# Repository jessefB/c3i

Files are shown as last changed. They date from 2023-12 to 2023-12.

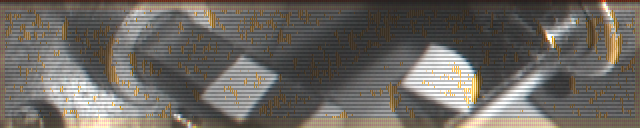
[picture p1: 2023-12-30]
code/raspiraw-master/res/out.1000.ppm.d.png

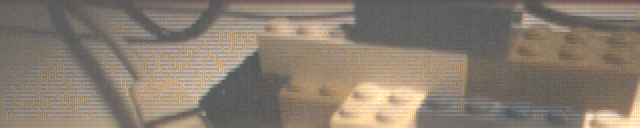
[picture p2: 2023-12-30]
code/raspiraw-master/res/out.0123.ppm.d.png

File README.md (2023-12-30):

# c3i
Composite to CSI2 Camera Interface (aka CCCI aka c3i)

### Purpose
Add a readily-available composite video camera (sold as 'backup cameras') to Raspberry Pi over a MIPI CSI2 camera interface

### Basic function
The ADV7280-M chip does all the magic, automatically detecting the composite video format (NTSC or PAL) and converting that to YCrCb 4:2:2 video stream. The -M variant of this chip adds a MIPI CSI2 conversion block, providing a single lane output MIPI data stream. Raspberry Pi's have dual lane MIPI channels, but according to [this](https://forums.raspberrypi.com/viewtopic.php?p=1717572&sid=e0199da8a1beeaa71a4631e8f8f0ca87#p1717572) thread, using lane 0 alone will work. The ADV7280-M has 8 composite video inputs, selectable by writing over i2c to the input selector register. Other than a couple voltage regulators and passive components, I designed this interface nearly identical to the recommended/typical use shown in the [datasheet](https://www.analog.com/media/en/technical-documentation/data-sheets/ADV7280.PDF). 

Parts can be found at [Digikey](https://www.digikey.com/en/mylists/list/8FBMX8EIKW). At the time of writing, this cost me just shy of $20 before shipping in parts. With 

## ** Currently under development ** 
I haven't gotten this working yet. Still in early stages of development.

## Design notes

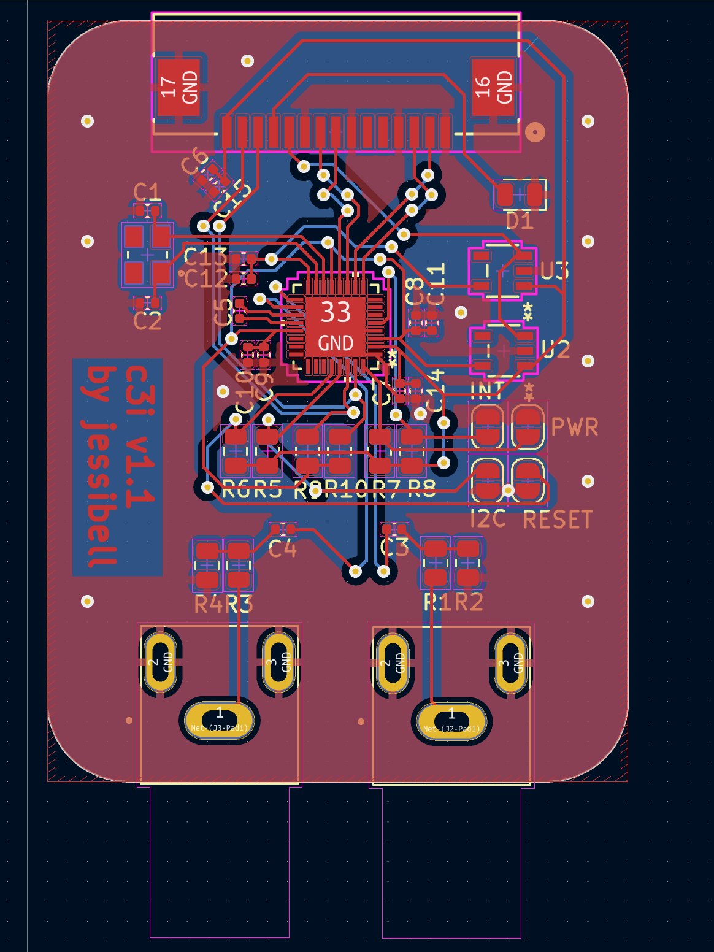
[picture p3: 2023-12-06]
PCB.png

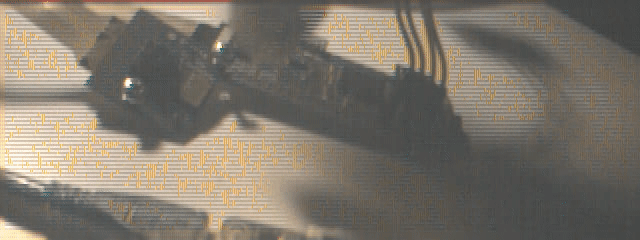
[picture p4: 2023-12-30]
code/raspiraw-master/res/out.360fps.25xSlower.2.anim.gif

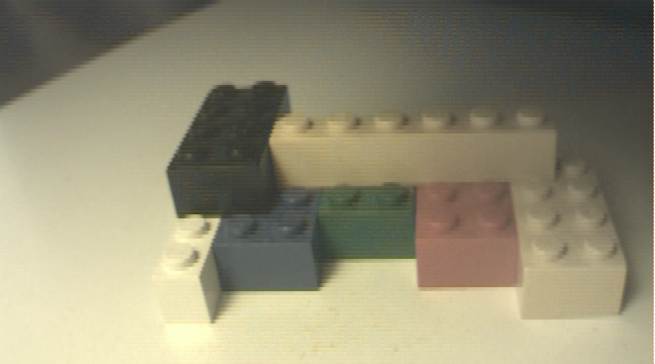
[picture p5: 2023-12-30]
code/raspiraw-master/res/Screenshot179.png

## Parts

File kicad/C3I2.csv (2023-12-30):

Source: | /Users/jessefryar/Library/Mobile Documents/com~apple~CloudDocs/Documents/projects/truck/electrical/cameras/C3I2/kicad/C3I2.kicad_sch
Date: | 2023 December 15, Friday 18:42:20
Tool: | Eeschema 7.0.8
Generator: | /Applications/KiCad/KiCad.app/Contents/SharedSupport/plugins/bom_csv_grouped_by_value_with_fp.py
Component Count: | 37
Ref | Qnty | Value | Cmp name | Footprint | Description | Vendor | DNP
C1, C2 | 2 | 47pF | C | Capacitor_SMD:C_0402_1005Metric | Unpolarized capacitor
C3, C4, C5, C6, C8, C9, C12, C14, C15 | 9 | 0.1uF | C | Capacitor_SMD:C_0402_1005Metric | Unpolarized capacitor
C7, C10, C11, C13 | 4 | 10nF | C | Capacitor_SMD:C_0402_1005Metric | Unpolarized capacitor
D1 | 1 | LED | LED | LED_SMD:LED_0805_2012Metric | Light emitting diode
J1 | 1 | 1-84952-5 | 1-84952-5 | components:conn15_1-84952-5_TEC
J2, J3 | 2 | PJRAN1X1U04X | PJRAN1X1U04X | components:SWITCHCRAFT_PJRAN1X1U04X
JP1, JP2, JP3, JP4 | 4 | Jumper_2_Open | Jumper_2_Open | Jumper:SolderJumper-2_P1.3mm_Open_RoundedPad1.0x1.5mm | Jumper, 2-pole, open
R1, R3 | 2 | 24 | R | Resistor_SMD:R_0805_2012Metric | Resistor
R2, R4 | 2 | 51 | R | Resistor_SMD:R_0805_2012Metric | Resistor
R5, R6, R7, R8 | 4 | 100k | R | Resistor_SMD:R_0805_2012Metric | Resistor
R9, R10 | 2 | 2.2k | R | Resistor_SMD:R_0805_2012Metric | Resistor
U1 | 1 | ADV7280BCPZ-M-RL | ADV7280BCPZ-M-RL | components:CP_32_12_ADI-M
U2, U3 | 2 | MIC5504-1.8YM5-TR | MIC5504-1.8YM5-TR | components:SOT23-5LD-PL-1_MCH
Y1 | 1 | 28.63636MHz | Crystal | components:XTAL_ABM8-28.63636MHZ-B2-T | Two pin crystal

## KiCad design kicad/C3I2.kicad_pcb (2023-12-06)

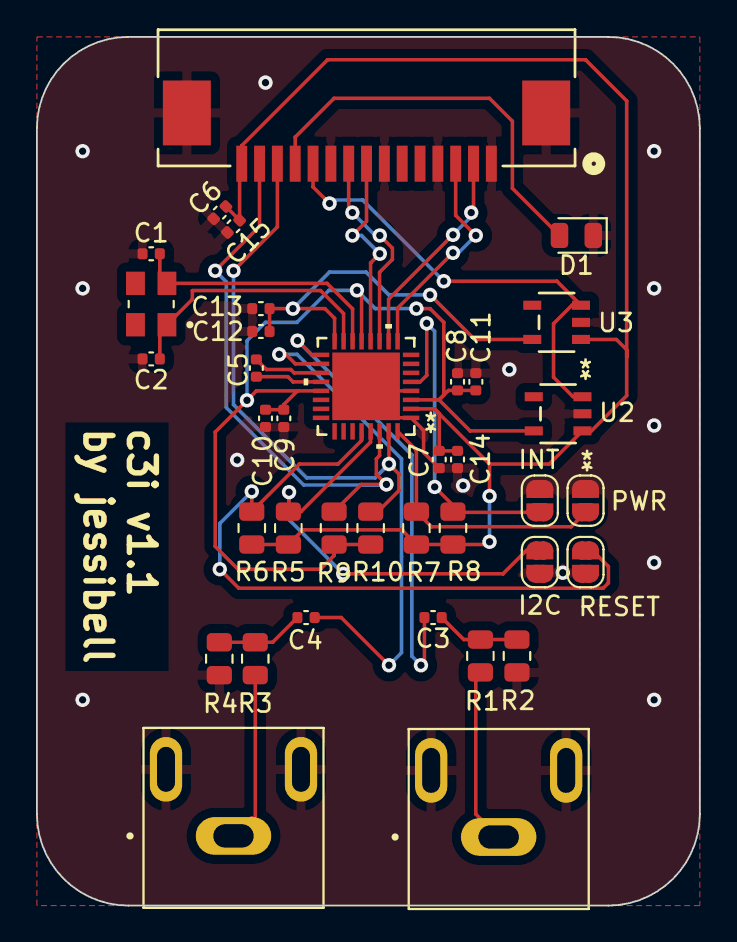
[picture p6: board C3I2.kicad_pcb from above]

Board: 2 copper layers, 36.8 x 48.3 mm, 37 parts (0 on the bottom side), 26 nets.

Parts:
C1, C2: 47pF; C_0402_1005Metric
C3, C4, C5, C6, C8, C9, C12, C14, C15: 0.1uF; C_0402_1005Metric
C7, C10, C11, C13: 10nF; C_0402_1005Metric
D1: LED; LED_0805_2012Metric
I2C: Jumper_2_Open; SolderJumper-2_P1.3mm_Open_RoundedPad1.0x1.5mm
INT: Jumper_2_Open; SolderJumper-2_P1.3mm_Open_RoundedPad1.0x1.5mm
J1: 1-84952-5; conn15_1-84952-5_TEC
J2, J3: PJRAN1X1U04X; SWITCHCRAFT_PJRAN1X1U04X
PWR: Jumper_2_Open; SolderJumper-2_P1.3mm_Open_RoundedPad1.0x1.5mm
R1, R3: 24; R_0805_2012Metric
R2, R4: 51; R_0805_2012Metric
R5, R6, R7, R8: 100k; R_0805_2012Metric
R9, R10: 2.2k; R_0805_2012Metric
RESET: Jumper_2_Open; SolderJumper-2_P1.3mm_Open_RoundedPad1.0x1.5mm
U1: ADV7280BCPZ-M-RL; CP_32_12_ADI-M
U2, U3: MIC5504-1.8YM5-TR; SOT23-5LD-PL-1_MCH
Y1: 28.63636MHz; XTAL_ABM8-28.63636MHZ-B2-T

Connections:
+1V8: C8.2, C9.2, C10.2, C11.2, R9.1, R10.1, U1.3 (DVDD), U1.13 (MVDD), U1.21 (AVDD), U2.5 (VOUT)
+3.3V: C6.2, C7.2, C14.1, C15.1, J1.15, R5.1, R6.1, R7.1, R8.1, U1.2 (DVDDIO), U2.1 (VIN), U3.1 (VIN)
Ain1: C3.2, U1.17 (AIN1)
Ain2: C4.2, U1.18 (AIN2)
GND: C1.1, C2.1, C6.1, C7.1, C8.1, C9.1, C10.1, C11.1, C12.1, C13.1, C14.2, C15.2, D1.1 (K), I2C.1 (A), INT.1 (A), J1.1, J1.4, J1.7, J1.10, J1.16, J1.17, J2.2, J2.3, J3.2, J3.3, PWR.1 (A), R2.1, R4.1, RESET.1 (A), U1.1 (DGND), U1.4 (DGND), U1.33 (EPAD), U2.2 (GND), U3.2 (GND)
I2C_ADD: I2C.2 (B), R5.2, U1.29 (ALSB)
I2C_SCL: J1.13, R10.2, U1.31 (SCLK)
I2C_SDA: J1.14, R9.2, U1.30 (SDATA)
INT: INT.2 (B), R8.2, U1.5 (*INTRQ)
LED_IND: D1.2 (A), J1.12
MIPI_CL_N: J1.8, U1.12 (CLKN)
MIPI_CL_P: J1.9, U1.11 (CLKP)
MIPI_D0_N: J1.2, U1.10 (D0N)
MIPI_D0_P: J1.3, U1.9 (D0P)
unnamed: C3.1, R1.2, R2.2
unnamed: C4.1, R3.2, R4.2
unnamed: J2.1, R1.1
unnamed: J3.1, R3.1
unnamed: C5.2, U1.20 (VREFN)
unnamed: C5.1, U1.19 (VREFP)
unnamed: C2.2, U1.15 (XTALN), Y1.1
unnamed: C1.2, U1.14 (XTALP), Y1.2
PVDD: C12.2, C13.2, U1.16 (PVDD), U3.5 (VOUT)
PWRDWN: PWR.2 (B), R7.2, U1.32 (*PWRDWN)
PWR_EN: J1.11, U2.3 (EN), U3.3 (EN)
RESET: R6.2, RESET.2 (B), U1.28 (*RESET)

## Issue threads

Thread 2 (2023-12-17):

Improper crystal wiring on PCB

jessefB, 2023-12-17:
Big dummy over here didn't check the data sheet and assumed which pins were which. Got it wrong. Of course.

Closed 2023-12-17.

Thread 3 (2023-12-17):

PCB Layout

jessefB, 2023-12-17:
- Composite signal input labels
- Crystal pinout (dummy over here didn't check the data sheet)
- Composite connectors are wired backwards (data sheet didn't specify very well)
- Regs power enable broken out (or tied to 3.3V)
- Power LED (3.3V and 1.8V)
- Test pads broken out (on bottom?)
- RCA jack cutouts
- Tidy labels
-

jessefB, 2023-12-29:
Fixed:
Composite signal input labels
Crystal pinout (dummy over here didn't check the data sheet)
Composite connectors are wired backwards (data sheet didn't specify very well)
Regs power enable broken out (or tied to 3.3V)
Power LED (3.3V and 1.8V)
Test pads broken out (on bottom?)
RCA jack cutouts (unnecessary)
Tidy labels

Closed 2023-12-29.

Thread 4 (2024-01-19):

PCB issues

jessefB, 2024-01-19:
C7 and C14 labels are reversed
3.3V/Lin regs enable/PWR enable jumper is connected wrong

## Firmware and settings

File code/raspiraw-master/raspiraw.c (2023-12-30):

/*
Copyright (c) 2015, Raspberry Pi Foundation
Copyright (c) 2015, Dave Stevenson
All rights reserved.

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
THIS SOFTWARE IS PROVIDED BY THE COPYRIGHT HOLDERS AND CONTRIBUTORS "AS IS" AND
ANY EXPRESS OR IMPLIED WARRANTIES, INCLUDING, BUT NOT LIMITED TO, THE IMPLIED
WARRANTIES OF MERCHANTABILITY AND FITNESS FOR A PARTICULAR PURPOSE ARE
DISCLAIMED. IN NO EVENT SHALL THE COPYRIGHT HOLDER OR CONTRIBUTORS BE LIABLE FOR
ANY DIRECT, INDIRECT, INCIDENTAL, SPECIAL, EXEMPLARY, OR CONSEQUENTIAL DAMAGES
(INCLUDING, BUT NOT LIMITED TO, PROCUREMENT OF SUBSTITUTE GOODS OR SERVICES;
LOSS OF USE, DATA, OR PROFITS; OR BUSINESS INTERRUPTION) HOWEVER CAUSED AND
ON ANY THEORY OF LIABILITY, WHETHER IN CONTRACT, STRICT LIABILITY, OR TORT
(INCLUDING NEGLIGENCE OR OTHERWISE) ARISING IN ANY WAY OUT OF THE USE OF THIS
SOFTWARE, EVEN IF ADVISED OF THE POSSIBILITY OF SUCH DAMAGE.
*/

#define VERSION_STRING "0.0.3"

#define _GNU_SOURCE
#include <ctype.h>
#include <fcntl.h>
#include <libgen.h>
#include <stdio.h>
#include <stdlib.h>
#include <string.h>

#include <linux/i2c-dev.h>
#include <linux/i2c.h>
#define I2C_SLAVE_FORCE 0x0706
#include "bcm_host.h"
#include "interface/vcos/vcos.h"

#include "interface/mmal/mmal.h"
#include "interface/mmal/mmal_buffer.h"
#include "interface/mmal/mmal_logging.h"
#include "interface/mmal/util/mmal_connection.h"
#include "interface/mmal/util/mmal_default_components.h"
#include "interface/mmal/util/mmal_util.h"
#include "interface/mmal/util/mmal_util_params.h"

#include "interface/vcsm/user-vcsm.h"

#include "RaspiCLI.h"

#include <sys/ioctl.h>

#include "raw_header.h"

#define DEFAULT_I2C_DEVICE 10
#define ALT_I2C_DEVICE	   0

#define I2C_DEVICE_NAME_LEN 13 // "/dev/i2c-XXX"+NULL

struct brcm_raw_header *brcm_header = NULL;

enum bayer_order
{
	// Carefully ordered so that an hflip is ^1,
	// and a vflip is ^2.
	BAYER_ORDER_BGGR,
	BAYER_ORDER_GBRG,
	BAYER_ORDER_GRBG,
	BAYER_ORDER_RGGB
};

struct sensor_regs
{
	uint16_t reg;
	uint16_t data;
};

struct mode_def
{
	struct sensor_regs *regs;
	int num_regs;
	int width;
	int height;
	MMAL_FOURCC_T encoding;
	enum bayer_order order;
	int native_bit_depth;
	uint8_t image_id;
	uint8_t data_lanes;
	int min_vts;
	int line_time_ns;
	uint32_t timing[5];
	uint32_t term[2];
	int black_level;

	int binning; /* Binning or skipping factor */
};

struct raspiraw_crop
{
	int hinc;
	int vinc;
	int width;
	int height;
	int left;
	int top;
};

struct sensor_def
{
	char *name;
	struct sensor_regs *common_init;
	int num_common_init;
	struct mode_def *modes;
	int num_modes;
	struct sensor_regs *stop;
	int num_stop_regs;

	uint8_t i2c_addr;   // Device I2C slave address
	int i2c_addressing; // Length of register address values
	int i2c_data_size;  // Length of register data to write

	//  Detecting the device
	int i2c_ident_length;	  // Length of I2C ID register
	uint16_t i2c_ident_reg;	  // ID register address
	uint16_t i2c_ident_value; // ID register value

	// Flip configuration
	uint16_t vflip_reg;		   // Register for VFlip
	int vflip_reg_bit;		   // Bit in that register for VFlip
	uint16_t hflip_reg;		   // Register for HFlip
	int hflip_reg_bit;		   // Bit in that register for HFlip
	int flips_dont_change_bayer_order; // Some sensors do not change the
					   // Bayer order by adjusting X/Y
					   // starts to compensate.

	uint16_t exposure_reg;
	int exposure_reg_num_bits;

	uint16_t vts_reg;
	int vts_reg_num_bits;

	uint16_t gain_reg;
	int gain_reg_num_bits;

	int (*set_crop)(const struct sensor_def *, struct mode_def *, const struct raspiraw_crop *cfg);
};

// The process first loads the cleaned up dump of the registers
// than updates the known registers to the proper values
// based on: http://www.seeedstudio.com/wiki/images/3/3c/Ov5647_full.pdf
enum operation
{
	EQUAL, // Set bit to value
	SET,   // Set bit
	CLEAR, // Clear bit
	XOR    // Xor bit
};

void modReg(struct mode_def *mode, uint16_t reg, int startBit, int endBit, int value, enum operation op);

#define NUM_ELEMENTS(a) (sizeof(a) / sizeof(a[0]))

#include "adv7282m_modes.h"
#include "imx219_modes.h"
#include "imx477_modes.h"
#include "ov5647_modes.h"

const struct sensor_def *sensors[] = { &ov5647, &imx219, &adv7282, &imx477, NULL };

enum
{
	CommandHelp,
	CommandMode,
	CommandHFlip,
	CommandVFlip,
	CommandExposure,
	CommandGain,
	CommandOutput,
	CommandWriteHeader,
	CommandTimeout,
	CommandSaveRate,
	CommandBitDepth,
	CommandCameraNum,
	CommandExposureus,
	CommandI2cBus,
	CommandAwbGains,
	CommandRegs,
	CommandHinc,
	CommandVinc,
	CommandFps,
	CommandWidth,
	CommandHeight,
	CommandLeft,
	CommandTop,
	CommandVts,
	CommandLine,
	CommandWriteHeader0,
	CommandWriteHeaderG,
	CommandWriteTimestamps,
	CommandWriteEmpty,
	CommandDecodeMetadata,
	CommandAwb,
	CommandNoPreview,
	CommandProcessing,
	CommandPreview,
	CommandFullScreen,
	CommandOpacity,
	CommandProcessingYUV,
	CommandOutputYUV,
};

static COMMAND_LIST cmdline_commands[] = {
	// clang-format off
	{ CommandHelp,            "-help",           "?",    "This help information", 0 },
	{ CommandMode,            "-mode",           "md",   "Set sensor mode <mode>", 1 },
	{ CommandHFlip,           "-hflip",          "hf",   "Set horizontal flip", 0 },
	{ CommandVFlip,           "-vflip",          "vf",   "Set vertical flip", 0 },
	{ CommandExposure,        "-ss",             "e",    "Set the sensor exposure time (not calibrated units)", 0 },
	{ CommandGain,            "-gain",           "g",    "Set the sensor gain code (not calibrated units)", 0 },
	{ CommandOutput,          "-output",         "o",    "Set the output filename", 0 },
	{ CommandWriteHeader,     "-header",         "hd",   "Write the BRCM header to the output file", 0 },
	{ CommandTimeout,         "-timeout",        "t",    "Time (in ms) before shutting down (if not specified, set to 5s)", 1 },
	{ CommandSaveRate,        "-saverate",       "sr",   "Save every Nth frame", 1 },
	{ CommandBitDepth,        "-bitdepth",       "b",    "Set output raw bit depth (8, 10, 12 or 16, if not specified, set to sensor native)", 1 },
	{ CommandCameraNum,       "-cameranum",      "c",    "Set camera number to use (0=CAM0, 1=CAM1).", 1 },
	{ CommandExposureus,      "-expus",          "eus",  "Set the sensor exposure time in micro seconds.", -1 },
	{ CommandI2cBus,          "-i2c",            "y",    "Set the I2C bus to use.", -1 },
	{ CommandAwbGains,        "-awbgains",       "awbg", "Set the AWB gains to use.", 1 },
	{ CommandRegs,            "-regs",           "r",    "Change (current mode) regs", 0 },
	{ CommandHinc,            "-hinc",           "hi",   "Set horizontal odd/even inc reg", -1 },
	{ CommandVinc,            "-vinc",           "vi",   "Set vertical odd/even inc reg", -1 },
	{ CommandFps,             "-fps",            "f",    "Set framerate regs", -1 },
	{ CommandWidth,           "-width",          "w",    "Set current mode width", -1 },
	{ CommandHeight,          "-height",         "h",    "Set current mode height", -1 },
	{ CommandLeft,            "-left",           "lt",   "Set current mode left", -1 },
	{ CommandTop,             "-top",            "tp",   "Set current mode top", -1 },
	{ CommandWriteHeader0,    "-header0",        "hd0",  "Sets filename to write the BRCM header to", 0 },
	{ CommandWriteHeaderG,    "-headerg",        "hdg",  "Sets filename to write the .pgm header to", 0 },
	{ CommandWriteTimestamps, "-tstamps",        "ts",   "Sets filename to write timestamps to", 0 },
	{ CommandWriteEmpty,      "-empty",          "emp",  "Write empty output files", 0 },
	{ CommandDecodeMetadata,  "-metadata",       "m",    "Decode register metadata", 0 },
	{ CommandAwb,             "-awb",            "awb",  "Use a simple grey-world AWB algorithm", 0 },
	{ CommandNoPreview,       "-nopreview",      "n",    "Do not send the stream to the display", 0 },
	{ CommandProcessing,      "-processing",     "P",    "Pass images into an image processing function", 0 },
	{ CommandPreview,         "-preview",        "p",    "Preview window settings <'x,y,w,h'>", 1 },
	{ CommandFullScreen,      "-fullscreen",     "fs",   "Fullscreen preview mode", 0 },
	{ CommandOpacity,         "-opacity",        "op",   "Preview window opacity (0-255)", 1 },
	{ CommandProcessingYUV,   "-processing_yuv", "PY",   "Pass processed YUV images into an image processing function", 0 },
	{ CommandOutputYUV,       "-output_yuv", "oY", "Set the output filename for YUV data", 0 },
	// clang-format on
};

static int cmdline_commands_size = sizeof(cmdline_commands) / sizeof(cmdline_commands[0]);

typedef struct pts_node
{
	int idx;
	int64_t pts;
	struct pts_node *nxt;
} * PTS_NODE_T;

#define DEFAULT_PREVIEW_LAYER 3

typedef struct raspiraw_params
{
	struct raspiraw_crop crop;
	int mode;
	int hflip;
	int vflip;
	int exposure;
	int gain;
	char *output;
	int capture;
	int write_header;
	int timeout;
	int saverate;
	int bit_depth;
	int camera_num;
	int exposure_us;
	int i2c_bus;
	double awb_gains_r;
	double awb_gains_b;
	char *regs;
	double fps;
	char *write_header0;
	char *write_headerg;
	char *write_timestamps;
	int write_empty;
	PTS_NODE_T ptsa;
	PTS_NODE_T ptso;
	int decodemetadata;
	int awb;
	int no_preview;
	int processing;
	int fullscreen; // 0 is use previewRect, non-zero to use full screen
	int opacity;	// Opacity of window - 0 = transparent, 255 = opaque
	MMAL_RECT_T
	preview_window; // Destination rectangle for the preview window.
	int capture_yuv;
	char *output_yuv;
	int processing_yuv;
} RASPIRAW_PARAMS_T;

typedef struct
{
	RASPIRAW_PARAMS_T *cfg;

	MMAL_POOL_T *rawcam_pool;
	MMAL_PORT_T *rawcam_output;

	MMAL_POOL_T *isp_ip_pool;
	MMAL_PORT_T *isp_ip;

	MMAL_QUEUE_T *awb_queue;
	int awb_thread_quit;
	MMAL_PARAMETER_AWB_GAINS_T wb_gains;

	MMAL_QUEUE_T *processing_queue;
	int processing_thread_quit;
} RASPIRAW_CALLBACK_T;

typedef struct
{
	RASPIRAW_PARAMS_T *cfg;

	MMAL_POOL_T *isp_op_pool;
	MMAL_PORT_T *isp_output;

	MMAL_POOL_T *vr_ip_pool;
	MMAL_PORT_T *vr_ip;

	MMAL_QUEUE_T *processing_yuv_queue;
	int processing_yuv_thread_quit;
} RASPIRAW_ISP_CALLBACK_T;

void update_regs(const struct sensor_def *sensor, struct mode_def *mode, int hflip, int vflip, int exposure, int gain);

static int i2c_rd(int fd, uint8_t i2c_addr, uint16_t reg, uint8_t *values, uint32_t n, const struct sensor_def *sensor)
{
	int err;
	uint8_t buf[2] = { reg >> 8, reg & 0xff };
	struct i2c_rdwr_ioctl_data msgset;
	struct i2c_msg msgs[2] = {
		{
		    .addr = i2c_addr,
		    .flags = 0,
		    .len = 2,
		    .buf = buf,
		},
		{
		    .addr = i2c_addr,
		    .flags = I2C_M_RD,
		    .len = n,
		    .buf = values,
		},
	};

	if (sensor->i2c_addressing == 1)
	{
		msgs[0].len = 1;
	}
	msgset.msgs = msgs;
	msgset.nmsgs = 2;

	err = ioctl(fd, I2C_RDWR, &msgset);
	// vcos_log_error("Read i2c addr %02X, reg %04X (len %d), value %02X,
	// err %d", i2c_addr, msgs[0].buf[0], msgs[0].len, values[0], err);
	if (err != (int)msgset.nmsgs)
		return -1;

	return 0;
}

const struct sensor_def *probe_sensor(int fd)
{
	const struct sensor_def **sensor_list = &sensors[0];
	const struct sensor_def *sensor = NULL;

	while (*sensor_list != NULL)
	{
		uint16_t reg = 0;
		sensor = *sensor_list;
		vcos_log_error("Probing sensor %s on addr %02X", sensor->name, sensor->i2c_addr);
		if (sensor->i2c_ident_length <= 2)
		{
			if (!i2c_rd(fd, sensor->i2c_addr, sensor->i2c_ident_reg, (uint8_t *)&reg,
				    sensor->i2c_ident_length, sensor))
			{
				if (reg == sensor->i2c_ident_value)
				{
					vcos_log_error("Found sensor %s at address %02X", sensor->name,
						       sensor->i2c_addr);
					break;
				}
			}
		}
		sensor_list++;
		sensor = NULL;
	}
	return sensor;
}

void send_regs(int fd, const struct sensor_def *sensor, const struct sensor_regs *regs, int num_regs)
{
	int i;
	for (i = 0; i < num_regs; i++)
	{
		if (regs[i].reg == 0xFFFF)
		{
			if (ioctl(fd, I2C_SLAVE_FORCE, regs[i].data) < 0)
			{
				vcos_log_error("Failed to set I2C address to %02X", regs[i].data);
			}
		}
		else if (regs[i].reg == 0xFFFE)
		{
			vcos_sleep(regs[i].data);
		}
		else
		{
			if (sensor->i2c_addressing == 1)
			{
				unsigned char msg[3] = { regs[i].reg, regs[i].data & 0xFF };
				int len = 2;

				if (sensor->i2c_data_size == 2)
				{
					msg[1] = (regs[i].data >> 8) & 0xFF;
					msg[2] = regs[i].data & 0xFF;
					len = 3;
				}
				if (write(fd, msg, len) != len)
				{
					vcos_log_error("Failed to write register index %d "
						       "(%02X val %02X)",
						       i, regs[i].reg, regs[i].data);
				}
			}
			else
			{
				unsigned char msg[4] = { regs[i].reg >> 8, regs[i].reg, regs[i].data };
				int len = 3;

				if (sensor->i2c_data_size == 2)
				{
					msg[2] = regs[i].data >> 8;
					msg[3] = regs[i].data;
					len = 4;
				}
				if (write(fd, msg, len) != len)
				{
					vcos_log_error("Failed to write register index %d", i);
				}
			}
		}
	}
}

void start_camera_streaming(const struct sensor_def *sensor, struct mode_def *mode, int fd)
{
	if (ioctl(fd, I2C_SLAVE_FORCE, sensor->i2c_addr) < 0)
	{
		vcos_log_error("Failed to set I2C address");
		return;
	}
	if (sensor->common_init)
		send_regs(fd, sensor, sensor->common_init, sensor->num_common_init);
	send_regs(fd, sensor, mode->regs, mode->num_regs);
	vcos_log_error("Now streaming...");
}
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
int main(int argc, char **argv)
{
	RASPIRAW_PARAMS_T cfg = { 0 };
	RASPIRAW_CALLBACK_T dev = { .cfg = &cfg, .rawcam_pool = NULL, .rawcam_output = NULL };
	RASPIRAW_ISP_CALLBACK_T yuv_cb = {
		.cfg = &cfg,
	};
	uint32_t encoding;
	const struct sensor_def *sensor;
	struct mode_def *sensor_mode = NULL;
	VCOS_THREAD_T awb_thread;
	VCOS_THREAD_T processing_thread;
	VCOS_THREAD_T processing_yuv_thread;
	char i2c_device_name[I2C_DEVICE_NAME_LEN];
	int i2c_fd;

	// Initialise any non-zero config values.
	cfg.exposure = -1;
	cfg.gain = -1;
	cfg.timeout = 5000;
	cfg.saverate = 20;
	cfg.bit_depth = -1;
	cfg.camera_num = -1;
	cfg.exposure_us = -1;
	cfg.i2c_bus = -1;
	cfg.crop.hinc = -1;
	cfg.crop.vinc = -1;
	cfg.fps = -1;
	cfg.crop.width = -1;
	cfg.crop.height = -1;
	cfg.crop.left = -1;
	cfg.crop.top = -1;
	cfg.opacity = 255;
	cfg.fullscreen = 1;

	bcm_host_init();
	vcos_log_register("RaspiRaw", VCOS_LOG_CATEGORY);

	if (argc == 1)
	{
		fprintf(stdout, "\n%s Camera App %s\n\n", basename(argv[0]), VERSION_STRING);

		raspicli_display_help(cmdline_commands, cmdline_commands_size);
		exit(-1);
	}

	// Parse the command line and put options in to our status structure
	if (parse_cmdline(argc, argv, &cfg))
	{
		exit(-1);
	}

	if (cfg.i2c_bus == -1)
	{
		snprintf(i2c_device_name, sizeof(i2c_device_name), "/dev/i2c-%d", DEFAULT_I2C_DEVICE);
		i2c_fd = open(i2c_device_name, O_RDWR);
		if (!i2c_fd)
		{
			snprintf(i2c_device_name, sizeof(i2c_device_name), "/dev/i2c-%d", ALT_I2C_DEVICE);
			i2c_fd = open(i2c_device_name, O_RDWR);
		}
	}
	else
	{
		snprintf(i2c_device_name, sizeof(i2c_device_name), "/dev/i2c-%d", cfg.i2c_bus);
		i2c_fd = open(i2c_device_name, O_RDWR);
	}

	if (!i2c_fd)
	{
		printf("Failed to open I2C device %s\n", i2c_device_name);
		return -1;
	}

	printf("Using I2C device %s\n", i2c_device_name);

	sensor = probe_sensor(i2c_fd);
	if (!sensor)
	{
		vcos_log_error("No sensor found. Aborting");
		return -1;
	}

	if (cfg.mode >= 0 && cfg.mode < sensor->num_modes)
	{
		sensor_mode = &sensor->modes[cfg.mode];
	}

	if (!sensor_mode)
	{
		vcos_log_error("Invalid mode %d - aborting", cfg.mode);
		return -2;
	}

	if (cfg.regs)
	{
		int r, b;
		char *p, *q;

		p = strtok(cfg.regs, ";");
		while (p)
		{
			vcos_assert(strlen(p) > 6);
			vcos_assert(p[4] == ',');
			vcos_assert(strlen(p) % 2);
			p[4] = '\0';
			q = p + 5;
			sscanf(p, "%4x", &r);
			while (*q)
			{
				vcos_assert(isxdigit(q[0]));
				vcos_assert(isxdigit(q[1]));

				sscanf(q, "%2x", &b);
				vcos_log_error("%04x: %02x", r, b);

				modReg(sensor_mode, r, 0, 7, b, EQUAL);

				++r;
				q += 2;
			}
			p = strtok(NULL, ";");
		}
	}

	if (cfg.crop.hinc >= 0 || cfg.crop.vinc >= 0 || cfg.crop.width > 0 || cfg.crop.width > 0 || cfg.crop.top >= 0 ||
	    cfg.crop.left >= 0)
	{
		if (sensor->set_crop)
		{
			if (sensor->set_crop(sensor, sensor_mode, &cfg.crop))
			{
				vcos_log_error("Failed setting manual crops. Aborting");
				return -1;
			}
		}
		else
		{
			vcos_log_error("This sensor does not currently support "
				       "manual cropping settings. Aborting");
			return -1;
		}
	}

	if (cfg.fps > 0)
	{
		int n = 1000000000 / (sensor_mode->line_time_ns * cfg.fps);
		modReg(sensor_mode, sensor->vts_reg + 0, 0, 7, n >> 8, EQUAL);
		modReg(sensor_mode, sensor->vts_reg + 1, 0, 7, n & 0xFF, EQUAL);
	}

	if (cfg.bit_depth == -1)
	{
		cfg.bit_depth = sensor_mode->native_bit_depth;
	}

	if (cfg.write_headerg && (cfg.bit_depth != sensor_mode->native_bit_depth))
	{
		// needs change after fix for
		// https://github.com/6by9/raspiraw/issues/2
		vcos_log_error("--headerG supported for native bit depth only");
		exit(-1);
	}

	if (cfg.exposure_us != -1)
	{
		cfg.exposure = ((int64_t)cfg.exposure_us * 1000) / sensor_mode->line_time_ns;
		vcos_log_error("Setting exposure to %d from time %dus", cfg.exposure, cfg.exposure_us);
	}

	update_regs(sensor, sensor_mode, cfg.hflip, cfg.vflip, cfg.exposure, cfg.gain);
	if (sensor_mode->encoding == 0)
		encoding = order_and_bit_depth_to_encoding(sensor_mode->order, cfg.bit_depth);
	else
		encoding = sensor_mode->encoding;
	if (!encoding)
	{
		vcos_log_error("Failed to map bitdepth %d and order %d into encoding\n", cfg.bit_depth,
			       sensor_mode->order);
		return -3;
	}
	vcos_log_error("Encoding %08X", encoding);

	if (cfg.awb)
	{
		VCOS_STATUS_T vcos_status;
		printf("Setup awb thread\n");
		vcos_status = vcos_thread_create(&awb_thread, "awb-thread", NULL, awb_thread_task, &dev);
		if (vcos_status != VCOS_SUCCESS)
		{
			printf("Failed to create awb thread\n");
			return -4;
		}
		dev.awb_queue = mmal_queue_create();
		if (!dev.awb_queue)
		{
			printf("Failed to create awb queue\n");
			return -4;
		}
	}
	else
		printf("No AWB\n");

	if (cfg.processing)
	{
		VCOS_STATUS_T vcos_status;
		printf("Setup processing thread\n");
		vcos_status =
		    vcos_thread_create(&processing_thread, "processing-thread", NULL, processing_thread_task, &dev);
		if (vcos_status != VCOS_SUCCESS)
		{
			printf("Failed to create processing thread\n");
			return -4;
		}
		dev.processing_queue = mmal_queue_create();
		if (!dev.processing_queue)
		{
			printf("Failed to create processing queue\n");
			return -4;
		}
	}

	MMAL_COMPONENT_T *rawcam = NULL, *isp = NULL, *render = NULL;
	MMAL_STATUS_T status;
	MMAL_PORT_T *output = NULL;
	MMAL_POOL_T *pool = NULL, *yuv_pool = NULL;
	MMAL_PARAMETER_CAMERA_RX_CONFIG_T rx_cfg;
	MMAL_PARAMETER_CAMERA_RX_TIMING_T rx_timing;
	unsigned int i;

	bcm_host_init();
	vcos_log_register("RaspiRaw", VCOS_LOG_CATEGORY);

	status = mmal_component_create("vc.ril.rawcam", &rawcam);
	if (status != MMAL_SUCCESS)
	{
		vcos_log_error("Failed to create rawcam");
		return -1;
	}
	status = mmal_port_parameter_set_boolean(rawcam->output[0], MMAL_PARAMETER_ZERO_COPY, MMAL_TRUE);
	if (status != MMAL_SUCCESS)
	{
		vcos_log_error("Failed to set zero copy");
		goto component_disable;
	}

	status = mmal_component_create("vc.ril.isp", &isp);
	if (status != MMAL_SUCCESS)
	{
		vcos_log_error("Failed to create isp");
		goto component_destroy;
	}
	status = mmal_port_parameter_set_boolean(isp->input[0], MMAL_PARAMETER_ZERO_COPY, MMAL_TRUE);
	if (status != MMAL_SUCCESS)
	{
		vcos_log_error("Failed to set zero copy");
		goto component_disable;
	}
	status = mmal_port_parameter_set_boolean(isp->output[0], MMAL_PARAMETER_ZERO_COPY, MMAL_TRUE);
	if (status != MMAL_SUCCESS)
	{
		vcos_log_error("Failed to set zero copy");
		goto component_disable;
	}

	status = mmal_component_create(MMAL_COMPONENT_DEFAULT_VIDEO_RENDERER, &render);
	if (status != MMAL_SUCCESS)
	{
		vcos_log_error("Failed to create render");
		goto component_destroy;
	}
	status = mmal_port_parameter_set_boolean(render->input[0], MMAL_PARAMETER_ZERO_COPY, MMAL_TRUE);
	if (status != MMAL_SUCCESS)
	{
		vcos_log_error("Failed to set zero copy");
		goto component_disable;
	}

	output = rawcam->output[0];

	rx_cfg.hdr.id = MMAL_PARAMETER_CAMERA_RX_CONFIG;
	rx_cfg.hdr.size = sizeof(rx_cfg);
	status = mmal_port_parameter_get(output, &rx_cfg.hdr);
	if (status != MMAL_SUCCESS)
	{
		vcos_log_error("Failed to get cfg");
		goto component_destroy;
	}
	if (sensor_mode->encoding || cfg.bit_depth == sensor_mode->native_bit_depth)
	{
		rx_cfg.unpack = MMAL_CAMERA_RX_CONFIG_UNPACK_NONE;
		rx_cfg.pack = MMAL_CAMERA_RX_CONFIG_PACK_NONE;
	}
	else
	{
		switch (sensor_mode->native_bit_depth)
		{
		case 8:
			rx_cfg.unpack = MMAL_CAMERA_RX_CONFIG_UNPACK_8;
			break;
		case 10:
			rx_cfg.unpack = MMAL_CAMERA_RX_CONFIG_UNPACK_10;
			break;
		case 12:
			rx_cfg.unpack = MMAL_CAMERA_RX_CONFIG_UNPACK_12;
			break;
		case 14:
			rx_cfg.unpack = MMAL_CAMERA_RX_CONFIG_UNPACK_16;
			break;
		case 16:
			rx_cfg.unpack = MMAL_CAMERA_RX_CONFIG_UNPACK_16;
			break;
		default:
			vcos_log_error("Unknown native bit depth %d", sensor_mode->native_bit_depth);
			rx_cfg.unpack = MMAL_CAMERA_RX_CONFIG_UNPACK_NONE;
			break;
		}
		switch (cfg.bit_depth)
		{
		case 8:
			rx_cfg.pack = MMAL_CAMERA_RX_CONFIG_PACK_8;
			break;
		case 10:
			rx_cfg.pack = MMAL_CAMERA_RX_CONFIG_PACK_RAW10;
			break;
		case 12:
			rx_cfg.pack = MMAL_CAMERA_RX_CONFIG_PACK_RAW12;
			break;
		case 14:
			rx_cfg.pack = MMAL_CAMERA_RX_CONFIG_PACK_14;
			break;
		case 16:
			rx_cfg.pack = MMAL_CAMERA_RX_CONFIG_PACK_16;
			break;
		default:
			vcos_log_error("Unknown output bit depth %d", cfg.bit_depth);
			rx_cfg.pack = MMAL_CAMERA_RX_CONFIG_PACK_NONE;
			break;
		}
	}
	vcos_log_error("Set pack to %d, unpack to %d", rx_cfg.unpack, rx_cfg.pack);
	if (sensor_mode->data_lanes)
		rx_cfg.data_lanes = sensor_mode->data_lanes;
	if (sensor_mode->image_id)
		rx_cfg.image_id = sensor_mode->image_id;
	status = mmal_port_parameter_set(output, &rx_cfg.hdr);
	if (status != MMAL_SUCCESS)
	{
		vcos_log_error("Failed to set cfg");
		goto component_destroy;
	}
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
